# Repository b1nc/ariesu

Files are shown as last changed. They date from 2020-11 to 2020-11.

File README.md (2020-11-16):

# ariesu アリエス

Ariesu keyboard PCB and plate files.
A 45%ish ergo-keyboard.
Warning: This keyboard has an extremely weird layout.

----

ariesu render
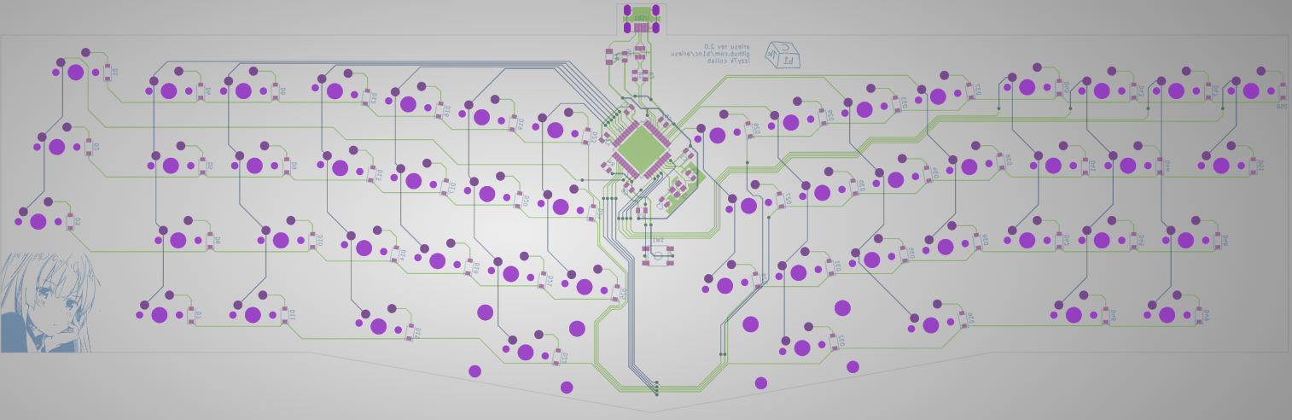
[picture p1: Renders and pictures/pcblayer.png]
ariesu pcb


The prototypes are in perfectly working condition.

There will not be a group-buy, however, all the PCB and case files are open-source
so feel free to order the parts yourself!

The PCB is the main part of this project, it's nothing fancy but it's something I'm
proud of. :^) (No backlits, sorry.)

Since the case files are stacked acrylic, it features a 0 degree typing angle, but
feel free to make a case for the PCB if you want something unique.

## Features (Very simple PCB) 
* Mini-B USB connection. (Yes, I know.)

* 51 keys.

* ATmega32U4

* MX-only no per key leds.

* No backlit leds.

## Thanks to
- ai03 for his PCB guide and hadi for his in-depth explanations.

- Izzy7k for sticking up with my bs and staying up with me.

- hadi's Youtube channel: https://www.youtube.com/channel/UCpWGAJr2AU7LPUwVYbBQZRg

- ai03's PCB guide: https://wiki.ai03.com/books/pcb-design/

## Addtional Items
I purchased most of the screws and standoffs from McMaster-Carr. Here are the parts
if you are going to use the stacked acrylic case in this project.

- Standoffs: Zinc-Plated Brass Female Threaded Hex Standoff 4.5mm Hex, 19mm Long, M3 x 0.5mm Thread (https://www.mcmaster.com/92080A014/)

- Screws: Brass Pan Head Slotted Screws M3 x 0.5mm Thread, 6mm Long (https://www.mcmaster.com/90928A301/)

- Bumpons: Adhesive-Back Bumpers Polyurethane, 1/2" Long, 1" Wide, 1/8" High, Durometer 65A, Black (https://www.mcmaster.com/95495K861/)

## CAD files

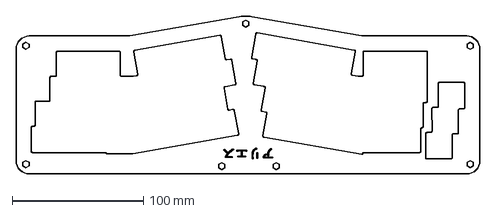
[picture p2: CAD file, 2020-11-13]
ariesuLayers/case_plate_top_2Rev.dxf
352.6 x 120.1 mm

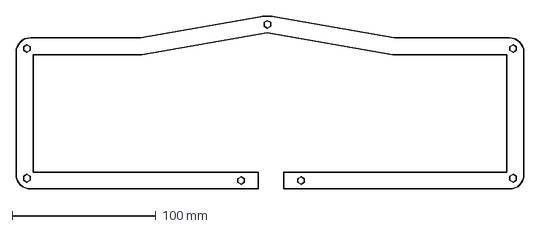
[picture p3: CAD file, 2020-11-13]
ariesuLayers/case_plate_layerRev.dxf
352.6 x 120.1 mm

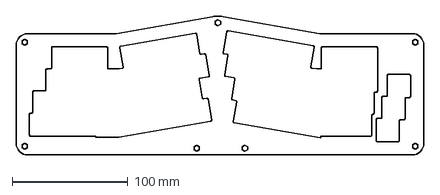
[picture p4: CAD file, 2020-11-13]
ariesuLayers/case_plate_top_1Rev.dxf
352.6 x 120.1 mm

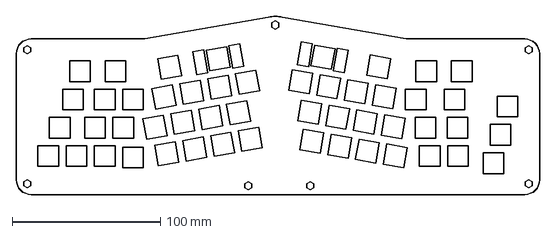
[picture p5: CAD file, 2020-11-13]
ariesuLayers/case_plate_switchRev.dxf
352.6 x 120.1 mm

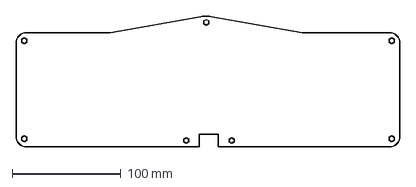
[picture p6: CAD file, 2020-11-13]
ariesuLayers/case_plate_backRev.dxf
352.6 x 120.1 mm

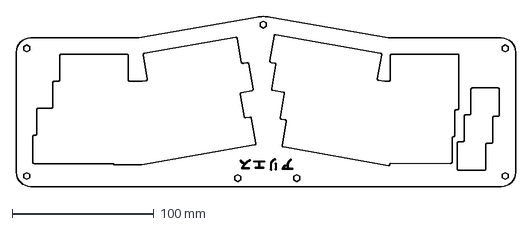
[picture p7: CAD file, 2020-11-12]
ariesuLayers/case_plate_top_2.dxf
352.6 x 120.1 mm

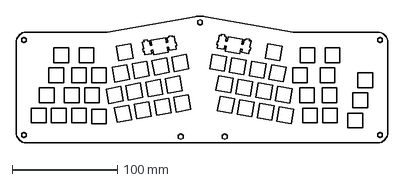
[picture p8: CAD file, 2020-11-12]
ariesuLayers/case_plate_switch.dxf
352.6 x 120.1 mm

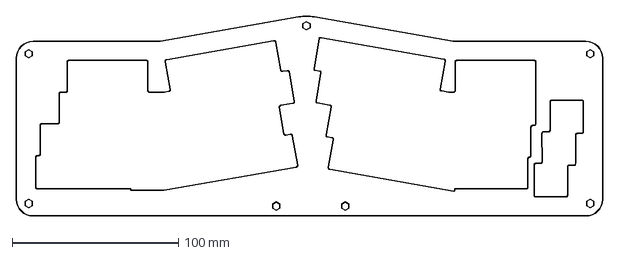
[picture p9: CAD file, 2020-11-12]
ariesuLayers/case_plate_top_1.dxf
352.6 x 120.1 mm

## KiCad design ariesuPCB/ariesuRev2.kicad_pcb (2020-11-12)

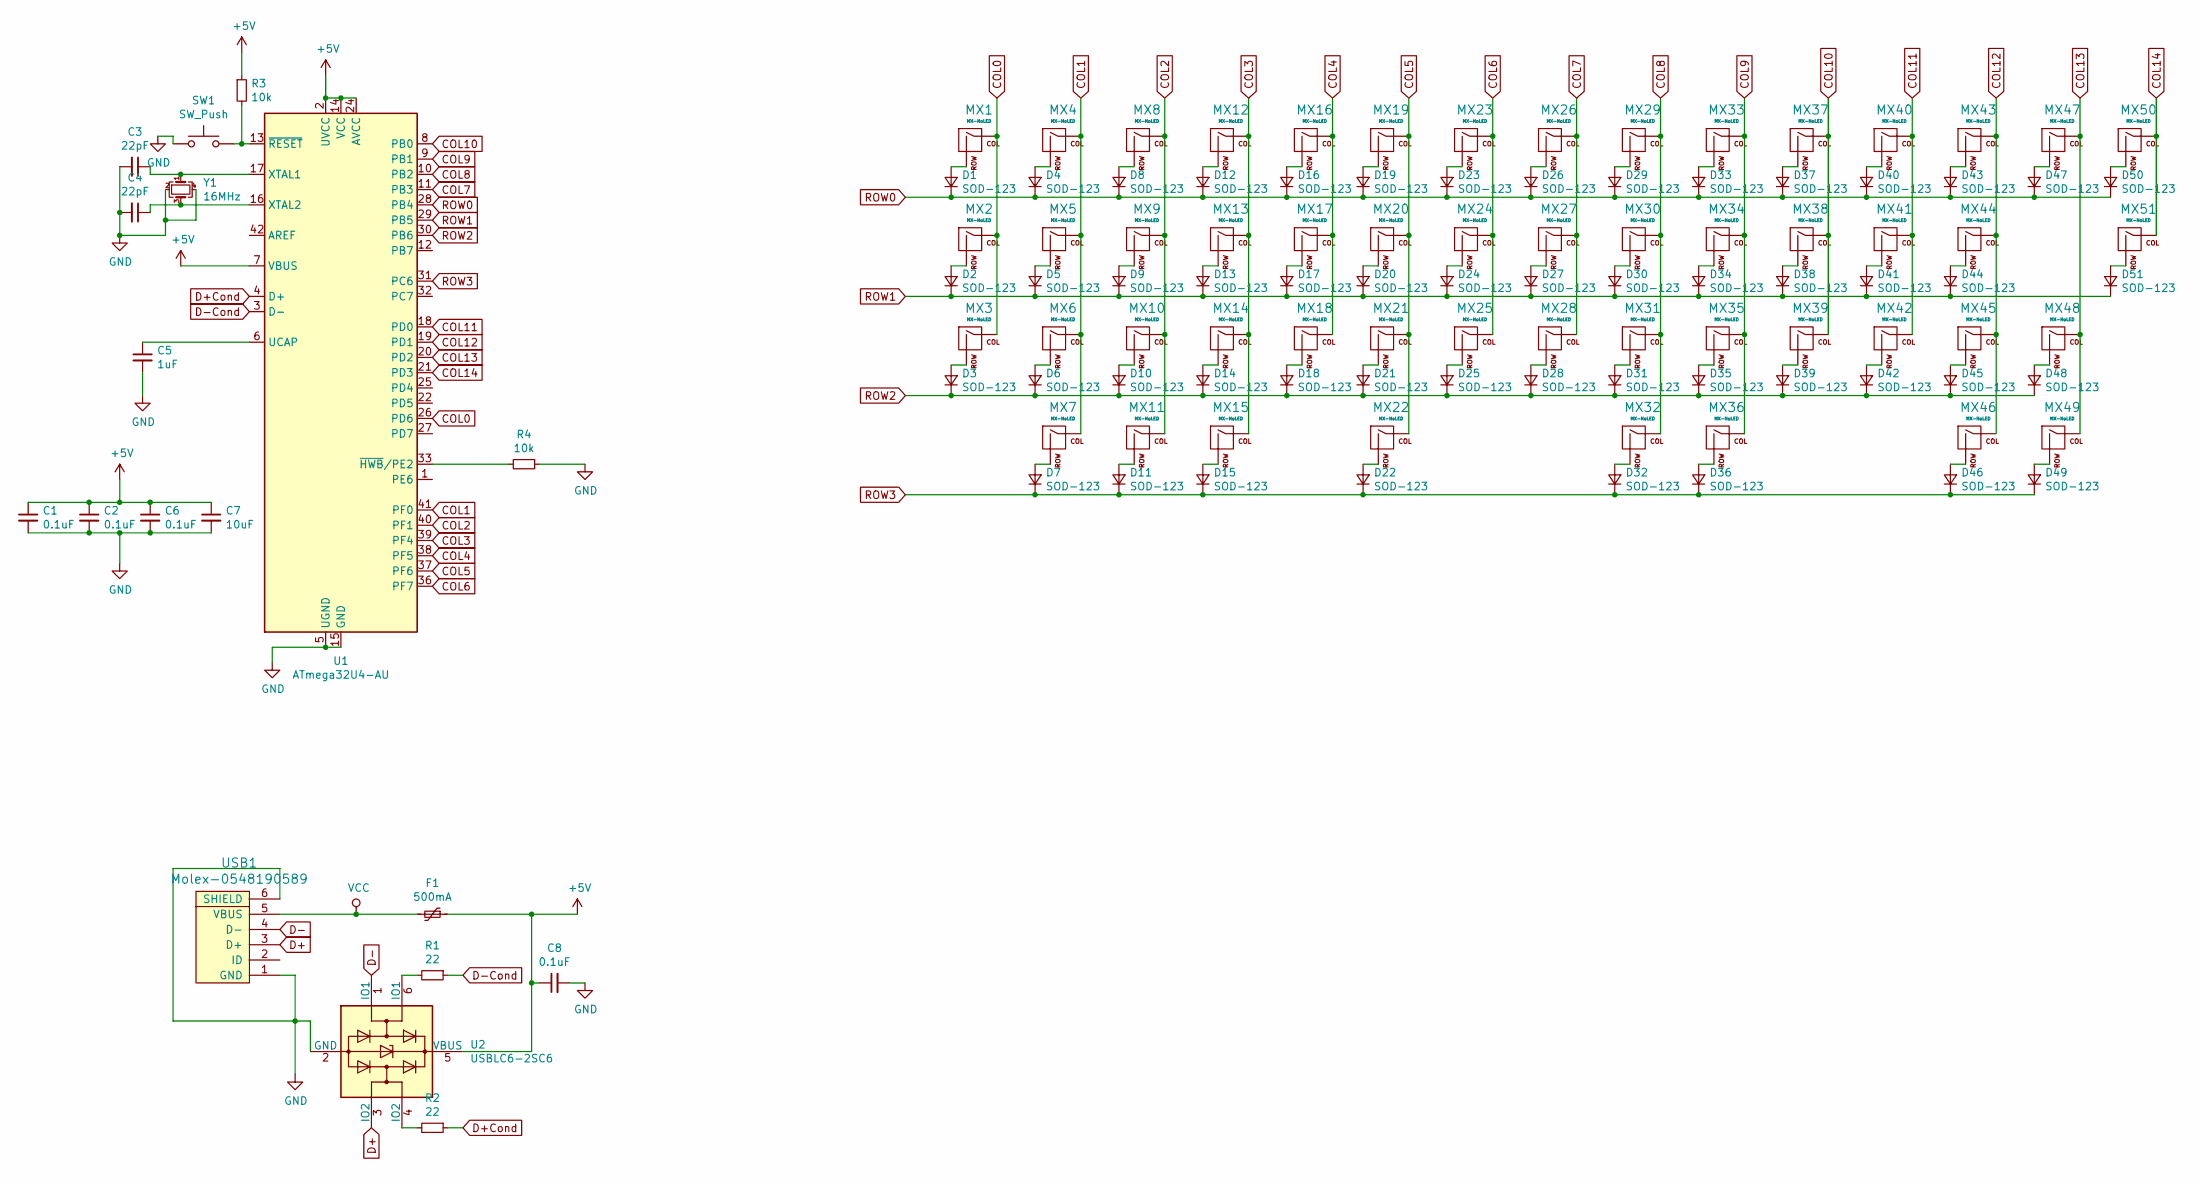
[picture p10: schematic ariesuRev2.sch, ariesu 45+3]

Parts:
C1, C2, C6, C8: 0.1uF; C_0805_2012Metric
C3, C4: 22pF; C_0805_2012Metric
C5: 1uF; C_0805_2012Metric
C7: 10uF; C_0805_2012Metric
D1, D2, D3, D4, D5, D6, D7, D8, D9, D10, D11, D12, D13, D14, D15, D16, D17, D18, D19, D20, D21, D22, D23, D24, D25, D26, D27, D28, D29, D30, D31, D32, D33, D34, D35, D36, D37, D38, D39, D40, D41, D42, D43, D44, D45, D46, D47, D48, D49, D50, D51: SOD-123; D_SOD-123
F1: 500mA; Fuse_1206_3216Metric
MX1, MX2, MX3, MX4, MX5, MX6, MX7, MX8, MX9, MX10, MX11, MX12, MX13, MX14, MX15, MX16, MX17, MX18, MX19, MX20, MX21, MX23, MX24, MX25, MX26, MX27, MX28, MX29, MX30, MX31, MX33, MX34, MX35, MX36, MX37, MX38, MX39, MX40, MX41, MX42, MX43, MX44, MX45, MX46, MX47, MX48, MX49, MX50, MX51: MX-NoLED; MXOnly-1U-NoLED
MX22, MX32: MX-NoLED; MXOnly-2.25U-ReversedStabilizers-NoLED
R1, R2: 22; R_0805_2012Metric
R3, R4: 10k; R_0805_2012Metric
SW1: SW_Push; SKQG-1155865
U1: ATmega32U4-AU; TQFP-44_10x10mm_P0.8mm
U2: USBLC6-2SC6; SOT-23-6
USB1: Molex-0548190589
Y1: 16MHz; Crystal_SMD_3225-4Pin_3.2x2.5mm

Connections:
+5V: C1.1, C2.1, C6.1, C7.1, C8.1, F1.1, R3.1, U1.2 (UVCC), U1.7 (VBUS), U1.14 (VCC), U1.24 (AVCC), U1.34 (VCC), U1.44 (AVCC), U2.5 (VBUS)
COL0: MX1.1 (COL), MX2.1 (COL), MX3.1 (COL), U1.26 (PD6)
COL1: MX4.1 (COL), MX5.1 (COL), MX6.1 (COL), MX7.1 (COL), U1.41 (PF0)
COL2: MX8.1 (COL), MX9.1 (COL), MX10.1 (COL), MX11.1 (COL), U1.40 (PF1)
COL3: MX12.1 (COL), MX13.1 (COL), MX14.1 (COL), MX15.1 (COL), U1.39 (PF4)
COL4: MX16.1 (COL), MX17.1 (COL), MX18.1 (COL), U1.38 (PF5)
COL5: MX19.1 (COL), MX20.1 (COL), MX21.1 (COL), MX22.1 (COL), U1.37 (PF6)
COL6: MX23.1 (COL), MX24.1 (COL), MX25.1 (COL), U1.36 (PF7)
COL7: MX26.1 (COL), MX27.1 (COL), MX28.1 (COL), U1.11 (PB3)
COL8: MX29.1 (COL), MX30.1 (COL), MX31.1 (COL), MX32.1 (COL), U1.10 (PB2)
COL9: MX33.1 (COL), MX34.1 (COL), MX35.1 (COL), MX36.1 (COL), U1.9 (PB1)
COL10: MX37.1 (COL), MX38.1 (COL), MX39.1 (COL), U1.8 (PB0)
COL11: MX40.1 (COL), MX41.1 (COL), MX42.1 (COL), U1.18 (PD0)
COL12: MX43.1 (COL), MX44.1 (COL), MX45.1 (COL), MX46.1 (COL), U1.19 (PD1)
COL13: MX47.1 (COL), MX48.1 (COL), MX49.1 (COL), U1.20 (PD2)
COL14: MX50.1 (COL), MX51.1 (COL), U1.21 (PD3)
D+: U2.3 (IO2), USB1.3 (D+)
D+Cond: R2.1, U1.4 (D+)
D-: U2.1 (IO1), USB1.4 (D-)
D-Cond: R1.1, U1.3 (D-)
GND: C1.2, C2.2, C3.2, C4.2, C5.2, C6.2, C7.2, C8.2, R4.1, SW1.1, U1.5 (UGND), U1.15 (GND), U1.23 (GND), U1.35 (GND), U1.43 (GND), U2.2 (GND), USB1.1 (GND), USB1.6 (SHIELD), Y1.2, Y1.4
unnamed: C3.1, U1.17 (XTAL1), Y1.1
unnamed: C4.1, U1.16 (XTAL2), Y1.3
unnamed: C5.1, U1.6 (UCAP)
unnamed: D1.2 (A), MX1.2 (ROW)
unnamed: D2.2 (A), MX2.2 (ROW)
unnamed: D3.2 (A), MX3.2 (ROW)
unnamed: D4.2 (A), MX4.2 (ROW)
unnamed: D5.2 (A), MX5.2 (ROW)
unnamed: D6.2 (A), MX6.2 (ROW)
unnamed: D7.2 (A), MX7.2 (ROW)
unnamed: D8.2 (A), MX8.2 (ROW)
unnamed: D9.2 (A), MX9.2 (ROW)
unnamed: D10.2 (A), MX10.2 (ROW)
unnamed: D11.2 (A), MX11.2 (ROW)
unnamed: D12.2 (A), MX12.2 (ROW)
unnamed: D13.2 (A), MX13.2 (ROW)
unnamed: D14.2 (A), MX14.2 (ROW)
unnamed: D15.2 (A), MX15.2 (ROW)
unnamed: D16.2 (A), MX16.2 (ROW)
unnamed: D17.2 (A), MX17.2 (ROW)
unnamed: D18.2 (A), MX18.2 (ROW)
unnamed: D19.2 (A), MX19.2 (ROW)
unnamed: D20.2 (A), MX20.2 (ROW)
unnamed: D21.2 (A), MX21.2 (ROW)
unnamed: D22.2 (A), MX22.2 (ROW)
unnamed: D23.2 (A), MX23.2 (ROW)
unnamed: D24.2 (A), MX24.2 (ROW)
unnamed: D25.2 (A), MX25.2 (ROW)
unnamed: D26.2 (A), MX26.2 (ROW)
unnamed: D27.2 (A), MX27.2 (ROW)
unnamed: D28.2 (A), MX28.2 (ROW)
unnamed: D29.2 (A), MX29.2 (ROW)
unnamed: D30.2 (A), MX30.2 (ROW)
unnamed: D31.2 (A), MX31.2 (ROW)
unnamed: D32.2 (A), MX32.2 (ROW)
unnamed: D33.2 (A), MX33.2 (ROW)
unnamed: D34.2 (A), MX34.2 (ROW)
unnamed: D35.2 (A), MX35.2 (ROW)
unnamed: D36.2 (A), MX36.2 (ROW)
unnamed: D37.2 (A), MX37.2 (ROW)
unnamed: D38.2 (A), MX38.2 (ROW)
unnamed: D39.2 (A), MX39.2 (ROW)
unnamed: D40.2 (A), MX40.2 (ROW)
unnamed: D41.2 (A), MX41.2 (ROW)
unnamed: D42.2 (A), MX42.2 (ROW)
unnamed: D43.2 (A), MX43.2 (ROW)
unnamed: D44.2 (A), MX44.2 (ROW)
unnamed: D45.2 (A), MX45.2 (ROW)
unnamed: D46.2 (A), MX46.2 (ROW)
unnamed: D47.2 (A), MX47.2 (ROW)
unnamed: D48.2 (A), MX48.2 (ROW)
unnamed: D49.2 (A), MX49.2 (ROW)
unnamed: D50.2 (A), MX50.2 (ROW)
unnamed: D51.2 (A), MX51.2 (ROW)
unnamed: R1.2, U2.6 (IO1)
unnamed: R2.2, U2.4 (IO2)
unnamed: R3.2, SW1.2, U1.13 (~RESET)
unnamed: R4.2, U1.33 (~HWB~/PE2)
ROW0: D1.1 (K), D4.1 (K), D8.1 (K), D12.1 (K), D16.1 (K), D19.1 (K), D23.1 (K), D26.1 (K), D29.1 (K), D33.1 (K), D37.1 (K), D40.1 (K), D43.1 (K), D47.1 (K), D50.1 (K), U1.28 (PB4)
ROW1: D2.1 (K), D5.1 (K), D9.1 (K), D13.1 (K), D17.1 (K), D20.1 (K), D24.1 (K), D27.1 (K), D30.1 (K), D34.1 (K), D38.1 (K), D41.1 (K), D44.1 (K), D51.1 (K), U1.29 (PB5)
ROW2: D3.1 (K), D6.1 (K), D10.1 (K), D14.1 (K), D18.1 (K), D21.1 (K), D25.1 (K), D28.1 (K), D31.1 (K), D35.1 (K), D39.1 (K), D42.1 (K), D45.1 (K), D48.1 (K), U1.30 (PB6)
ROW3: D7.1 (K), D11.1 (K), D15.1 (K), D22.1 (K), D32.1 (K), D36.1 (K), D46.1 (K), D49.1 (K), U1.31 (PC6)
VCC: F1.2, USB1.5 (VBUS)

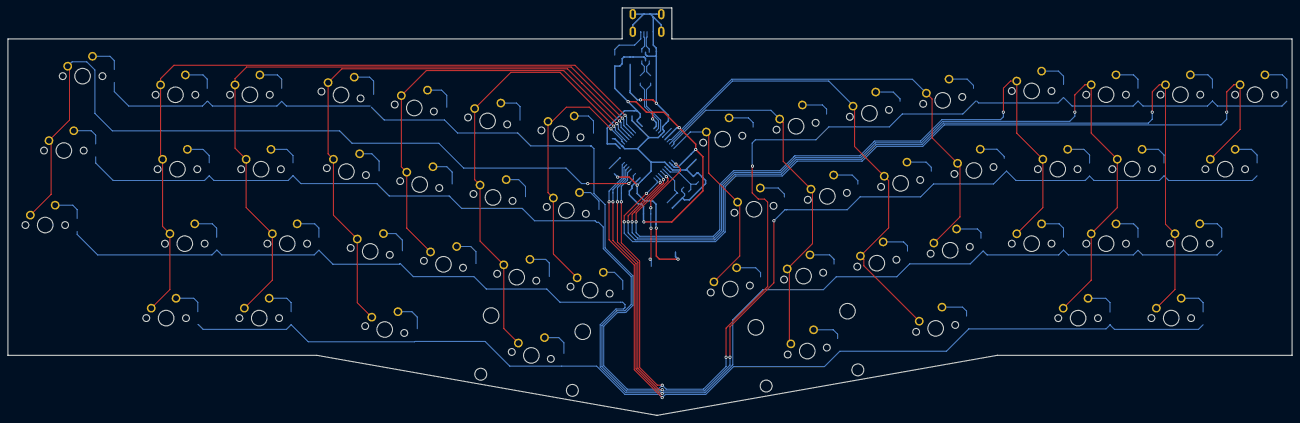
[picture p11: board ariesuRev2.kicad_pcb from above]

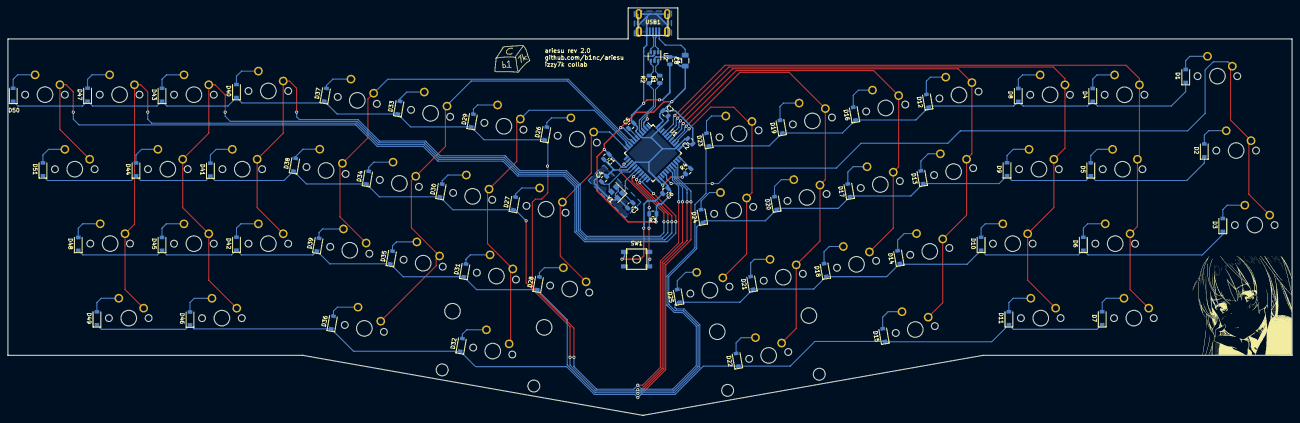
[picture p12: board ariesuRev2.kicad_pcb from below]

Board: 2 copper layers, 328.6 x 104.3 mm, 120 parts (69 on the bottom side), 84 nets.
